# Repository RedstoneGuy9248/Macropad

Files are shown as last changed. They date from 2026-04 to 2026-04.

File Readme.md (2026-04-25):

# Ridhim's Macropad
Ridhim's Macropad is a 9-key macropad with a EC11 rotary encoder running on an RPi Pico. (Made for Hack Club Fallout)

## Features:
- Cool looking case
- EC11 Rotary Encoder as a volume knob
- 9 Keys (Reprogrammable in Python)
- Connects using Micro-USB

### why?
I made this project as a bit of a more complex next project, compared to my [previous hardware project](https://github.com/RedstoneGuy9248/weatherStation), as i barely have any hardware experience and need practice to be able to build actual complex ones. (also for fallout lol). From this, I've learnt the basics of how to design PCBs in KiCAD, re-learnt Fusion 360 after like 4 years, and also understood a lot about how hardware made to like actual complete products are made. 

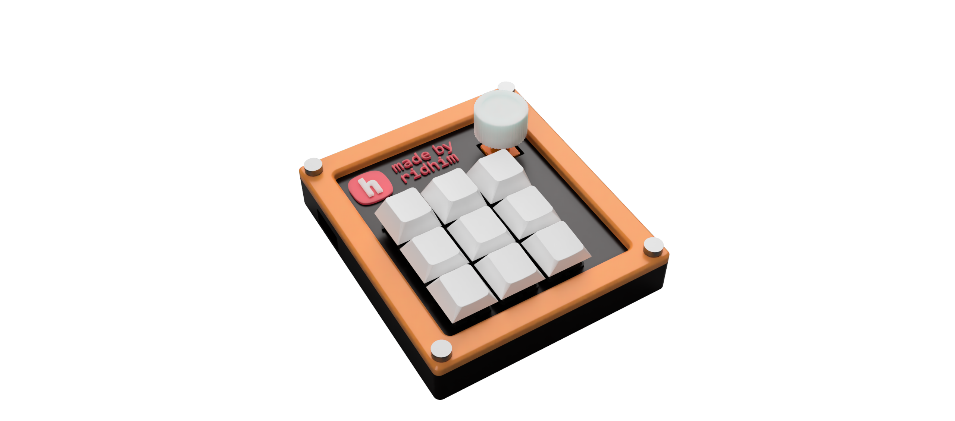
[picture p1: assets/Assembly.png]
Image of macropad fully assembled


## Assembly:
- Snap the switches into the plate
- Then the switches, diodes, rotary encoder, and RPi Pico should be soldered onto the pcb acccording to the schematic. 
- Place the plate with the pcb attached underneath it into the base and fit the micro usb port into its hole
- Place the top part, and then insert 4 M3*20mm screws into the holes and secure underneath with nuts
- Insert keycaps onto switches and dial onto rotary encoder

## Setup
- [Install CircuitPython on the RPi Pico](https://learn.adafruit.com/welcome-to-circuitpython/installing-circuitpython)
- Get an up to date copy of [KMK](https://github.com/KMKfw/kmk_firmware/archive/refs/heads/main.zip)
- Unzip it and drag the contents into the root of the usb drive corresponding to the RPi Pico
- Copy the main.py file from firmware/ of this repo into the same root folder

## Schematic

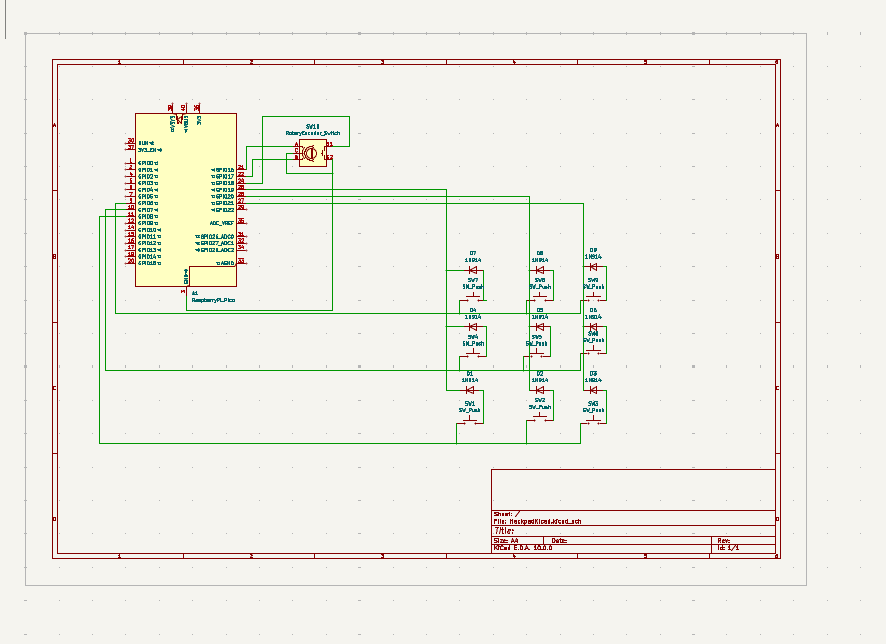
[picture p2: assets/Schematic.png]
Image of macropad schematic


## PCB

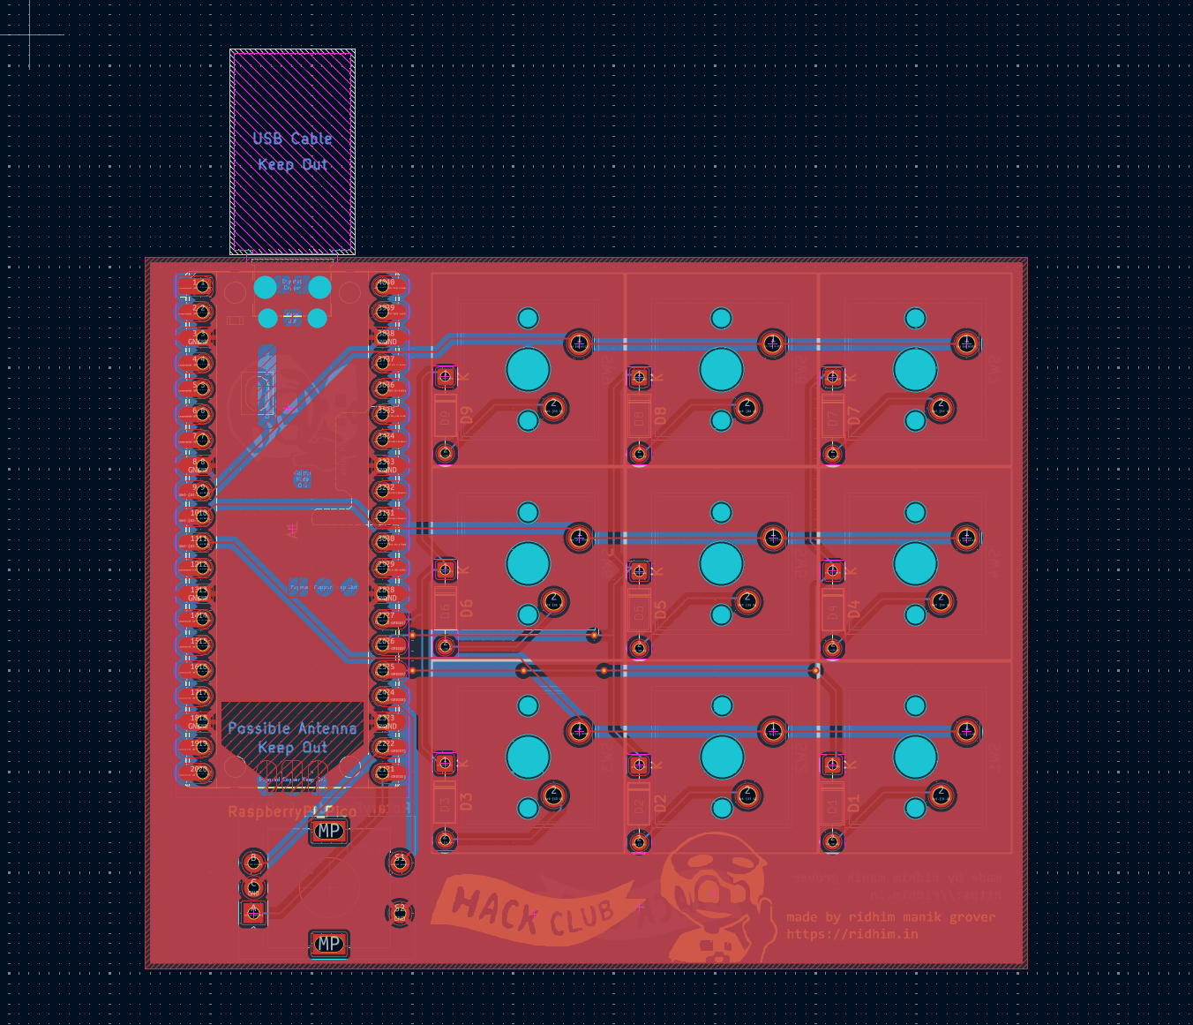
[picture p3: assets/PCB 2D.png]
Image of macropad PCB Flat

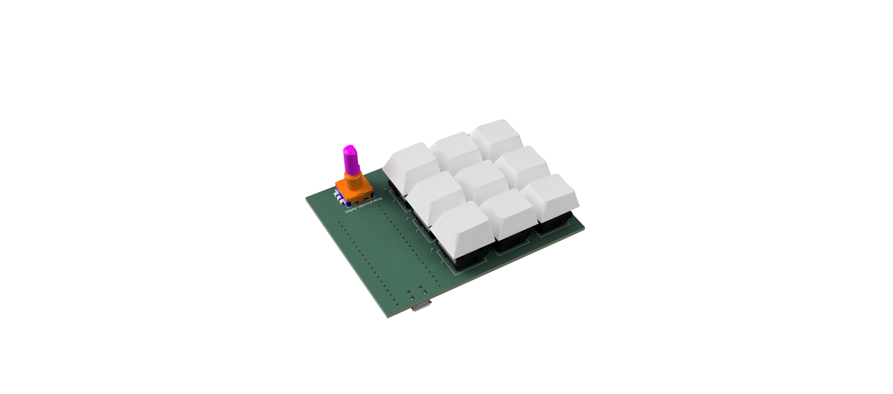
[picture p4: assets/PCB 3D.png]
Image of macropad PCB 3D

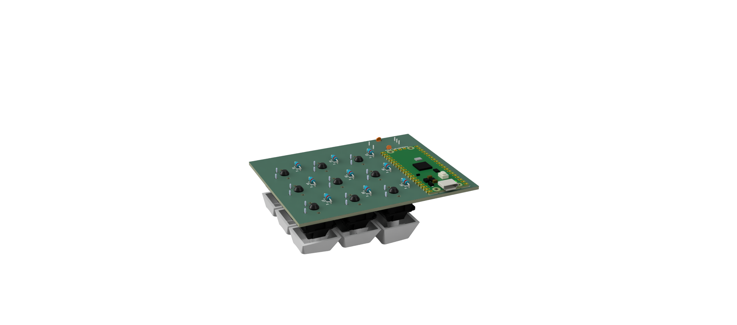
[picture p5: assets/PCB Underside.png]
Image of macropad PCB 3D Underside


## Bill Of Materials

The BOM is available [here](/BOM.csv)

## Zine

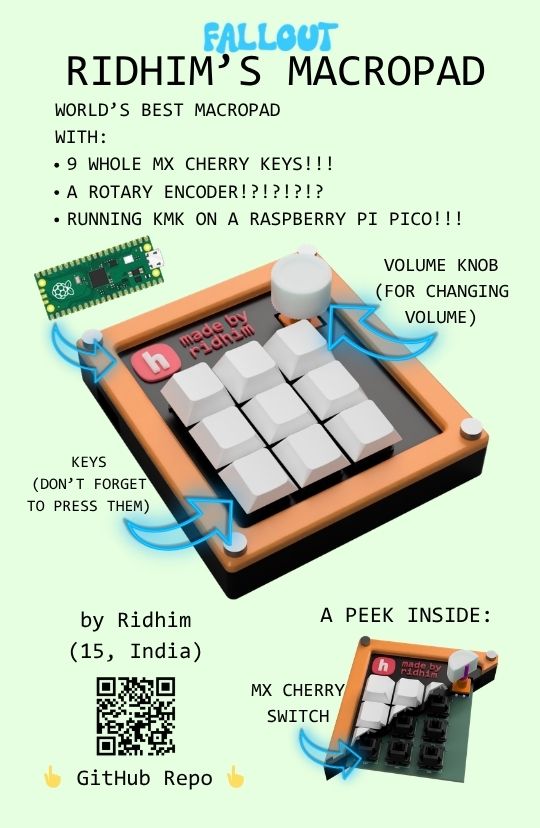
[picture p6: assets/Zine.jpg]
Image of Zine


(The PDF is available [here](/Ridhim%27s%20Macropad%20Zine.pdf))

## Note:

There are 2 variants of the plate available, one has a thickness of 1.5mm and the other is 3mm. The 3mm is the main one as it is the size specified in the Hackpad guide, and a 1.5mm 3D Printed plate would be very fragile.

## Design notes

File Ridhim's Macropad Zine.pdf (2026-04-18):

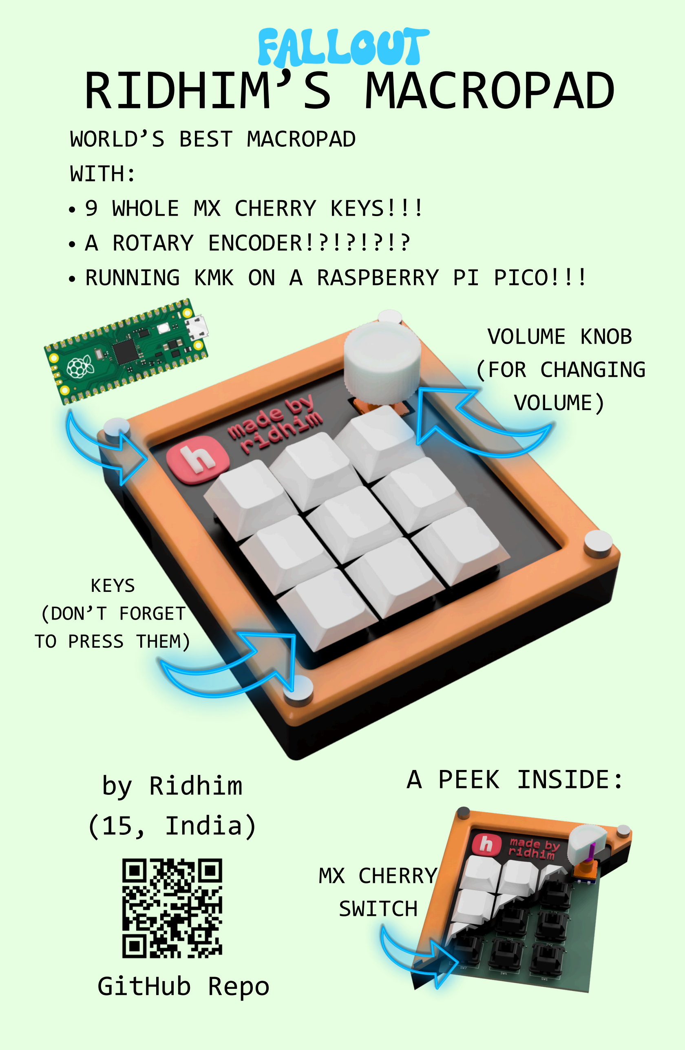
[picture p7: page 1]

RIDHIM’S MACROPAD WORLD’S BEST MACROPAD

WITH:
9 WHOLE MX CHERRY KEYS!!!
A ROTARY ENCODER!?!?!?!?
RUNNING KMK ON A RASPBERRY PI PICO!!!

by Ridhim
(15, India)

GitHub Repo

A PEEK INSIDE:

VOLUME KNOB
(FOR CHANGING
VOLUME)

KEYS
(DON’T FORGET
TO PRESS THEM)

MX CHERRY
SWITCH

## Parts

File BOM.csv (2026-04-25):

Quantity | Name | Price Per Piece | Total Price | Vendor | Vendor Link | Note
20* | 1N4148 Diode | 3 INR / 0.032 USD | 60INR / 0.65 USD | FlyRobo | https://www.flyrobo.in/1n4148-switching-diode-standard-75v-150ma-through-hole | *9 Needed but min order qty is 20
9 | MX Cherry Switch | 26 INR / 0.28 USD | 234 INR / 2.25 USD | Rajiv Electronics | https://rajivelectronics.com/productDetails/MCYQ
5* | PCBs | 37.04 INR / 0.4 USD | 185.19 INR / 2 USD | JLCPCB |  | *1 Needed but min order qty is 5
1 | Raspberry Pi Pico | 397 INR / 4.29 USD | 397 INR / 4.29 USD | RoboCraze | https://robocraze.com/products/raspberry-pi-pico
1 | Enclosure 3D Print | 914.13 INR / 9.87 USD | 914.13 INR / 9.87 USD * | JLCPCB |  | *Might be reduced if use print legion or ender 3
1 | EC11 Rotary Encoder | 44 INR / 0.48 USD | 44 INR / 0.48 USD | FlyRobo | https://www.flyrobo.in/ec11-rotary-encoder-with-switch-digital-potentiometer-20mm
20* | M3*20mm Screws | 2 INR / 0.022 USD | 40 INR / 0.43 USD | FlyRobo | https://www.flyrobo.in/m3x20mm-pan-philips-head-screw-10pcs | *4 Needed but min order qty is 20
20* | M3 Nut | 1.5 INR / 0.016 USD | 30 INR / 0.32 USD | FlyRobo | https://www.flyrobo.in/m3-ss-hex-nut-10pcs | *4 Needed but min order qty is 20
10* | Keycaps | 20 INR / 0.21 USD | 200 INR / 2.1 USD | Meckeys | https://meckeys.com/shop/accessories/keyboard-accessories/keycaps/blank-dsa-keycaps-1u/
_ | Shipping + Misc | 110 INR / 1.19 USD |  | Rajiv Electronics
 |  | 59 INR / 0.64 USD |  | Fly Robo
 |  | 50 INR / 0.54 USD |  | RoboCraze
 |  | 998.27 INR / 10.78 USD * |  | JLCPCB |  | *Might be reduced due to coupon
_ |  | 100 INR / 1.06 USD |  | Meckeys
 |  |  | 1317.27 INR / 13.98 USD
 | Total | _ | 3421.13 INR / 36.30 USD

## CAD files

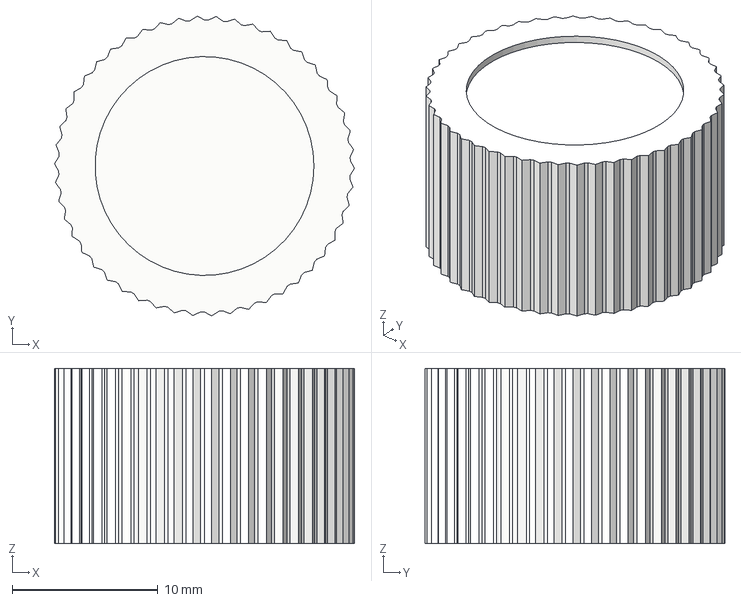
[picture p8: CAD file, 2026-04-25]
cad/Dial.step
20.6 x 20.5 x 12.0 mm
macropad v26
Dial

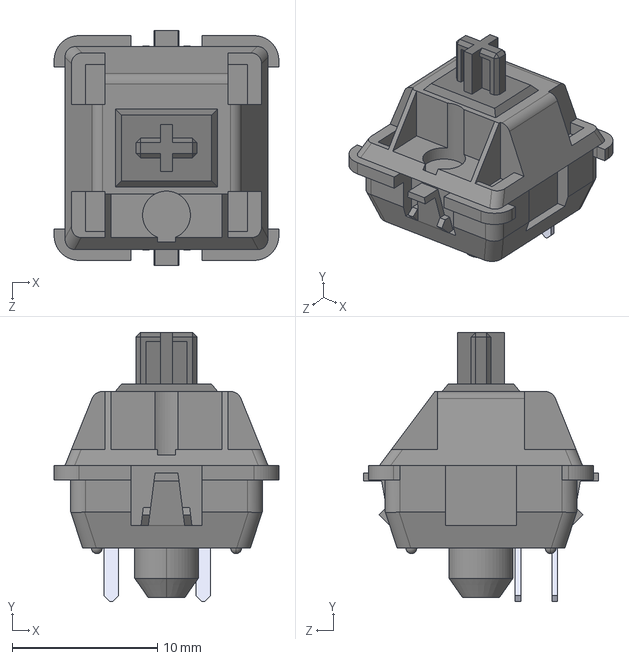
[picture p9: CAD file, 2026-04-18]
pcb/MX1A11NN--3DModel-STEP-510211.step
15.5 x 18.5 x 16.2 mm

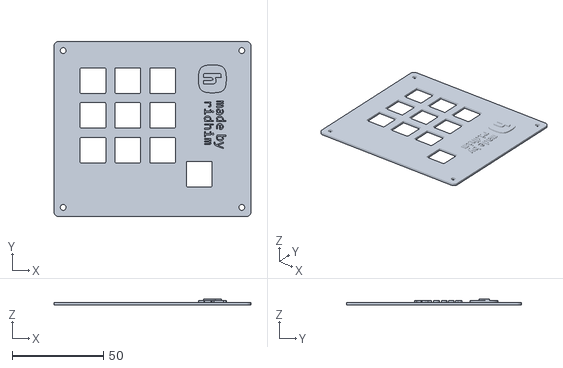
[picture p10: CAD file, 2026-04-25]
production/plate (1.5mm).stl
107.9 x 95.9 x 3.50

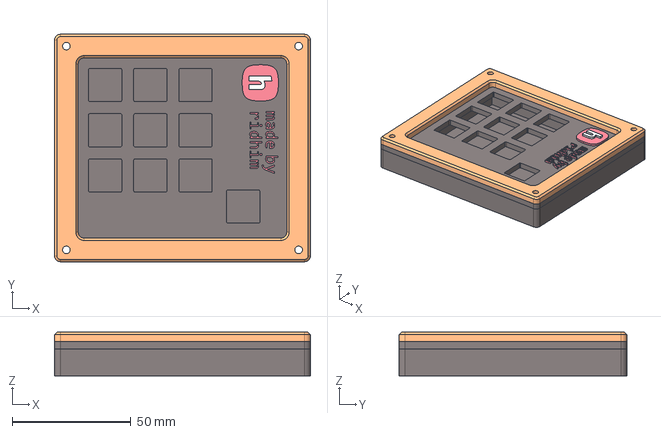
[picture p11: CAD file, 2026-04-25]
cad/macropad.step
107.9 x 95.9 x 18.4 mm

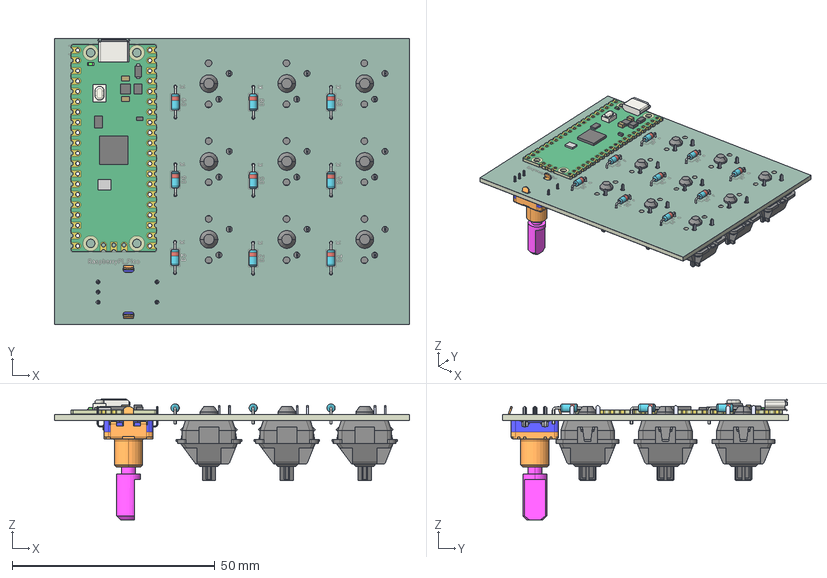
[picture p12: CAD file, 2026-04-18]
pcb/pcb_final.step
87.5 x 70.5 x 29.8 mm
D_DO-35_SOD27_P7.62mm_Horizontal x 9
RaspberryPi_Pico_Module_KiCad
MX1A11NN--3DModel-STEP-510211 x 9
ec11e18244a5
HackpadKicad_silkscreen x 2
HackpadKicad_soldermask x 2
HackpadKicad_PCB

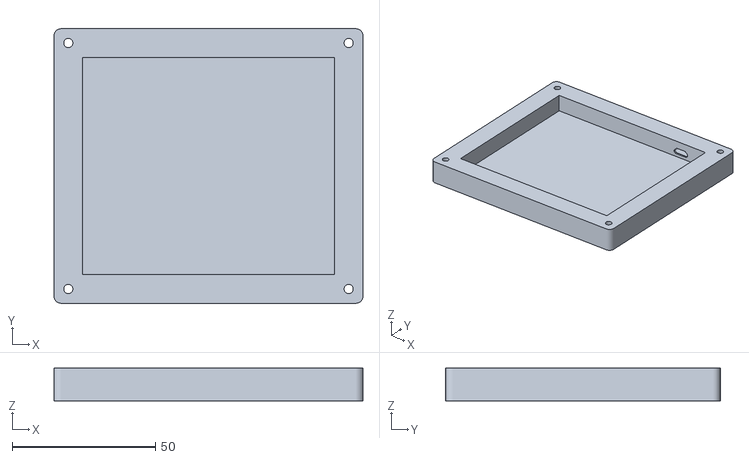
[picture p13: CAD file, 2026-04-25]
production/base.stl
107.9 x 95.9 x 11.4

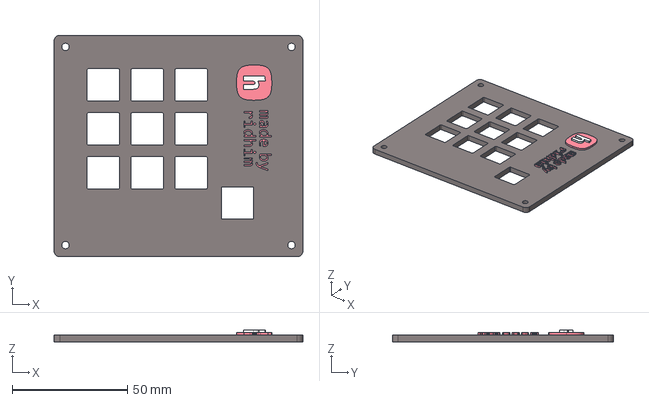
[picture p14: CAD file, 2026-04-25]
cad/plate.step
107.9 x 95.9 x 5.00 mm

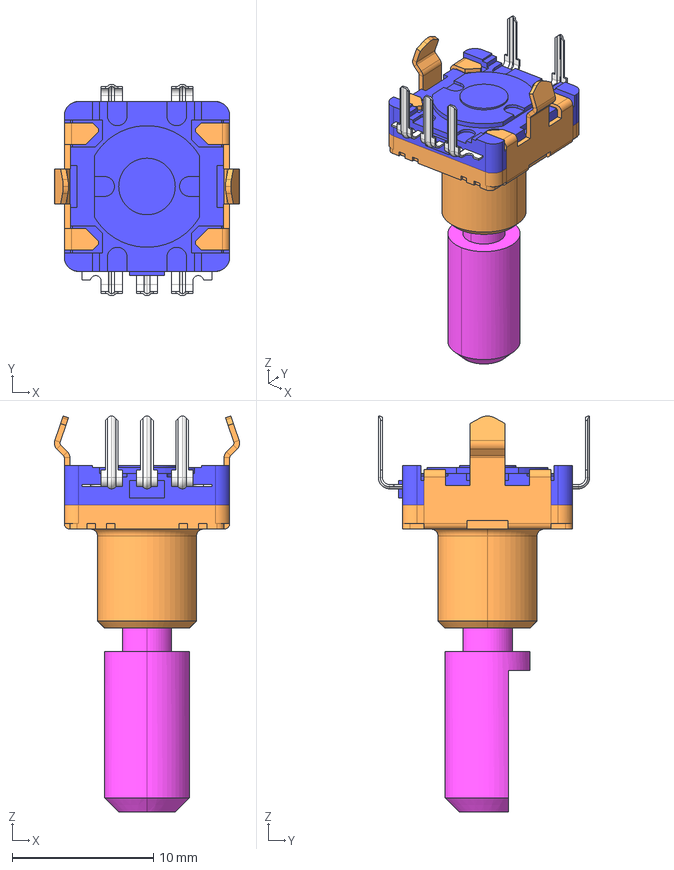
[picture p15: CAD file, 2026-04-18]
pcb/ec11e18244a5.stp
13.1 x 15.0 x 28.0 mm

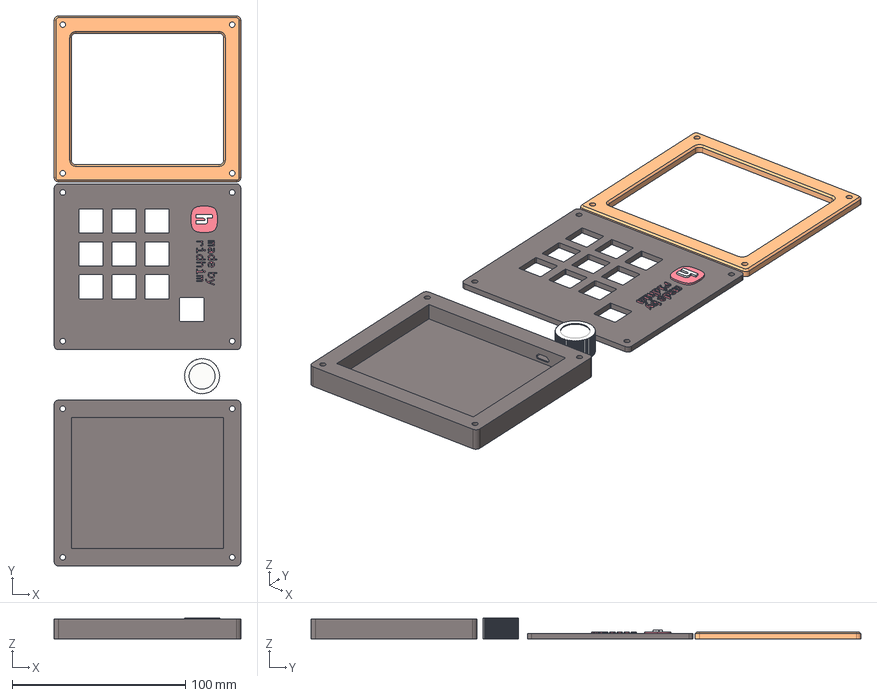
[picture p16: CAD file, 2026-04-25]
cad/Parts to print.step
107.9 x 317.9 x 12.0 mm
macropad v26
Dial

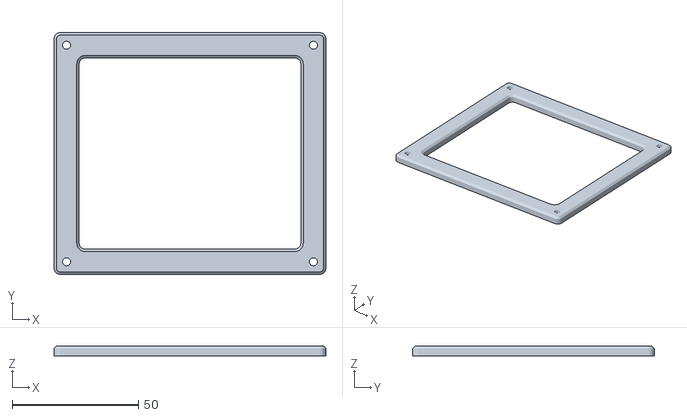
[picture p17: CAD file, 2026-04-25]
production/top.stl
107.9 x 95.9 x 4.00

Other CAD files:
production/dial.stl
production/plate.stl
cad/plate (1.5mm).step
cad/top.step
cad/base.step
cad/macropad.f3d
cad/parts to print.f3d

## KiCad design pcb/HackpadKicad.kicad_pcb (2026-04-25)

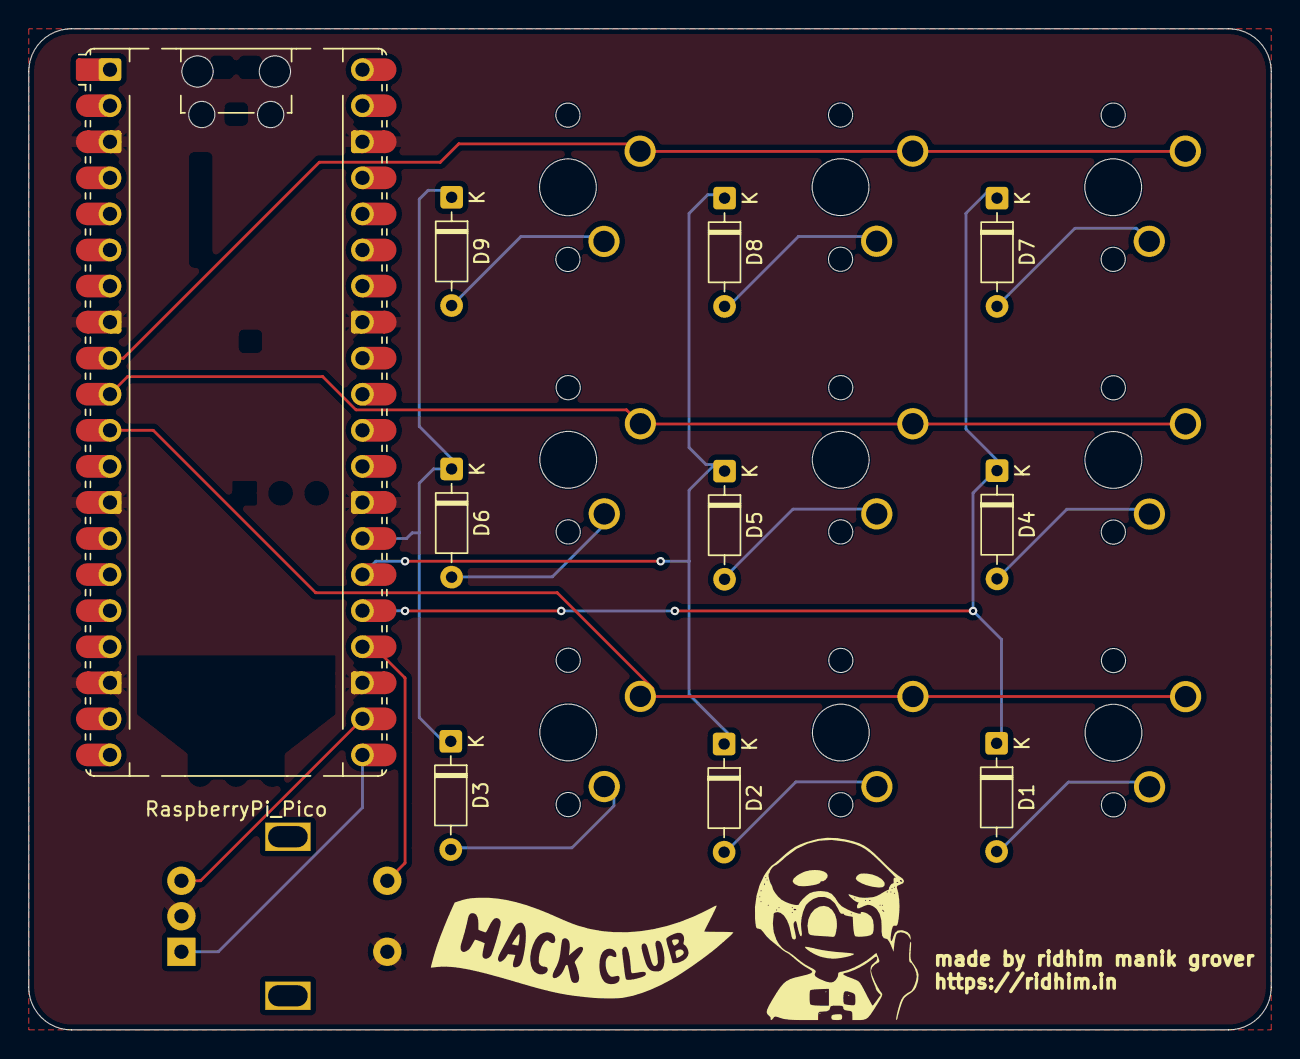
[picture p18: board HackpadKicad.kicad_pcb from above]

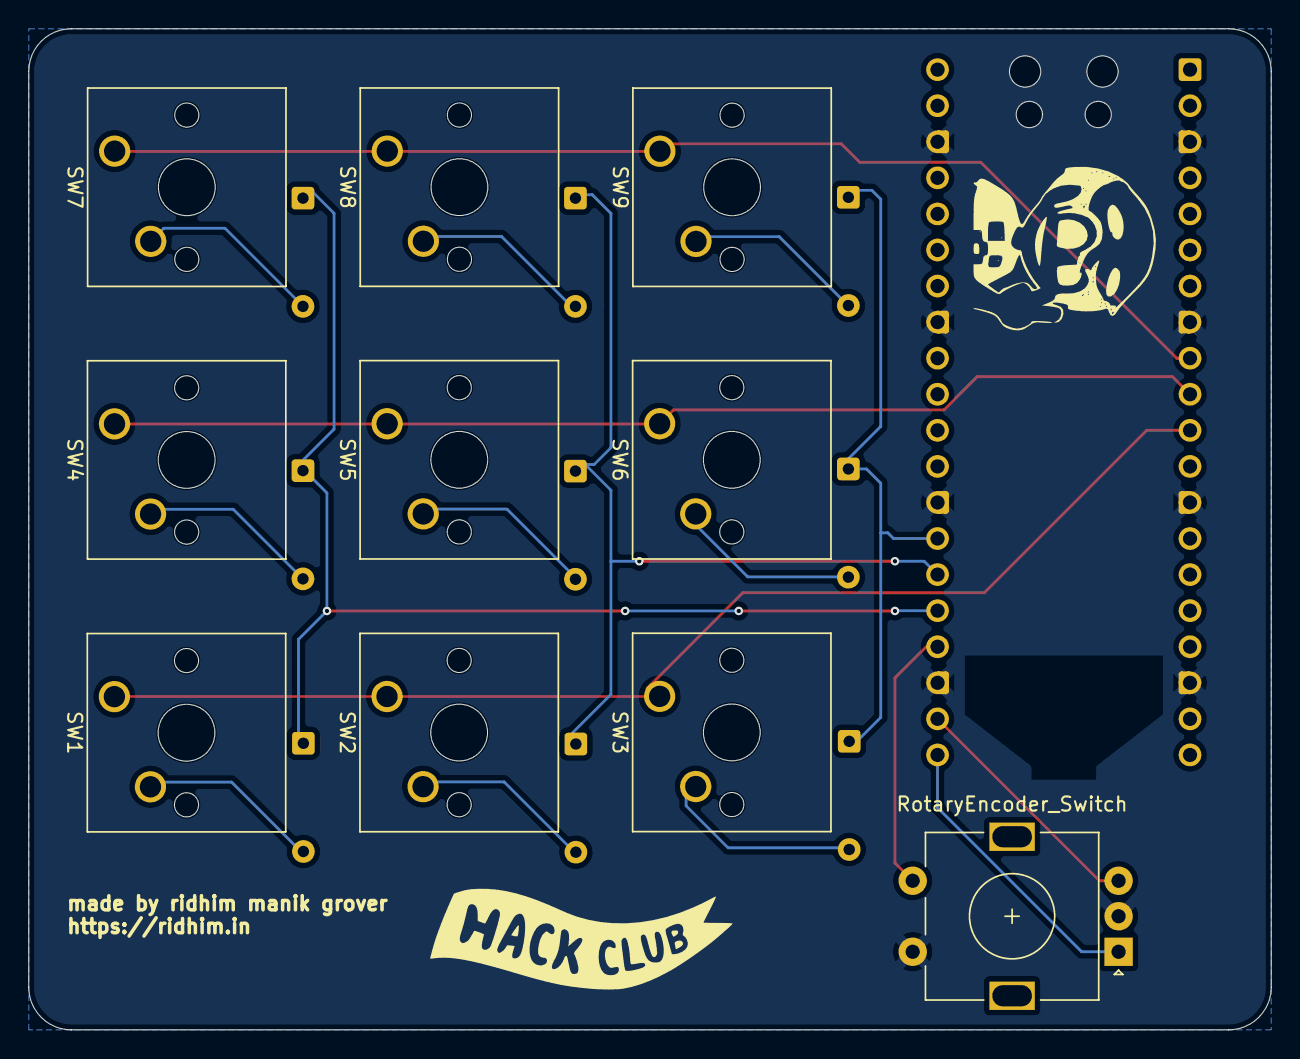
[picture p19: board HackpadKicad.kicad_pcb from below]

Board: 2 copper layers, 87.5 x 70.5 mm, 20 parts (10 on the bottom side), 19 nets.

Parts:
A1: RaspberryPi_Pico; RaspberryPi_Pico_Common_Unspecified
D1, D2, D3, D4, D5, D6, D7, D8, D9: 1N914; D_DO-35_SOD27_P7.62mm_Horizontal
SW1, SW2, SW3, SW4, SW5, SW6, SW7, SW8, SW9: SW_Push; SW_Cherry_MX_1.00u_PCB
SW10: RotaryEncoder_Switch; RotaryEncoder_Alps_EC11E-Switch_Vertical_H20mm

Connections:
GND: A1.3 (GND), A1.8 (GND), A1.13 (GND), A1.18 (GND), A1.23 (GND), A1.28 (GND), A1.33 (AGND), A1.38 (GND), SW10.C, SW10.S2
unnamed: A1.9 (GPIO6), SW7.1, SW8.1, SW9.1
unnamed: A1.10 (GPIO7), SW4.1, SW5.1, SW6.1
unnamed: A1.11 (GPIO8), SW1.1, SW2.1, SW3.1
unnamed: A1.21 (GPIO16), SW10.A
unnamed: A1.22 (GPIO17), SW10.B
unnamed: A1.24 (GPIO18), SW10.S1
unnamed: A1.25 (GPIO19), D1.1 (K), D4.1 (K), D7.1 (K)
unnamed: A1.26 (GPIO20), D2.1 (K), D5.1 (K), D8.1 (K)
unnamed: A1.27 (GPIO21), D3.1 (K), D6.1 (K), D9.1 (K)
unnamed: D1.2 (A), SW1.2
unnamed: D2.2 (A), SW2.2
unnamed: D3.2 (A), SW3.2
unnamed: D4.2 (A), SW4.2
unnamed: D5.2 (A), SW5.2
unnamed: D6.2 (A), SW6.2
unnamed: D7.2 (A), SW7.2
unnamed: D8.2 (A), SW8.2
unnamed: D9.2 (A), SW9.2

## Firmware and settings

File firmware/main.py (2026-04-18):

import board
from kmk.scanners import DiodeOrientation
from kmk.keys import KC
from kmk.kmk_keyboard import KMKKeyboard
from kmk.modules.macros import Press, Release, Tap, Macros, Delay
from kmk.modules.encoder import EncoderHandler
from kmk.extensions.media_keys import MediaKeys


keyboard = KMKKeyboard()
keyboard.extensions.append(MediaKeys())
encoder_handler = EncoderHandler()
macros = Macros()
keyboard.modules = [encoder_handler, macros]

keyboard.col_pins = (board.GP6, board.GP7, board.GP8)
keyboard.row_pins = (board.GP27, board.GP26, board.GP25)
keyboard.diode_orientation = DiodeOrientation.COL2ROW

encoder_handler.pins = ((board.GP21, board.GP22, board.GP24, False),)

encoder_handler.map = [((KC.VOLU, KC.VOLD, KC.MPLY),)]


# to be implemented later


REBOOT_INTO_WINDOWS = KC.MACRO(
    Tap(KC.LGUI(KC.N1)),
    Delay(2000),
    "./windows.sh",
    Tap(KC.ENTER)
)


keyboard.keymap = [[KC.N1, KC.N2, KC.N3], [KC.N4, KC.N5, KC.N6], [KC.N7, KC.N8, KC.N9]]

if __name__ == "__main__":
    keyboard.go()

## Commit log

2026-04-18 Add BOM
    [BOM.csv]
2026-04-18 Update Readme with plate variant information
2026-04-25 fix pcb clipping enclosure, filet pcb corners, add zine and why to readme
    [BOM.csv, Dial.step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]
